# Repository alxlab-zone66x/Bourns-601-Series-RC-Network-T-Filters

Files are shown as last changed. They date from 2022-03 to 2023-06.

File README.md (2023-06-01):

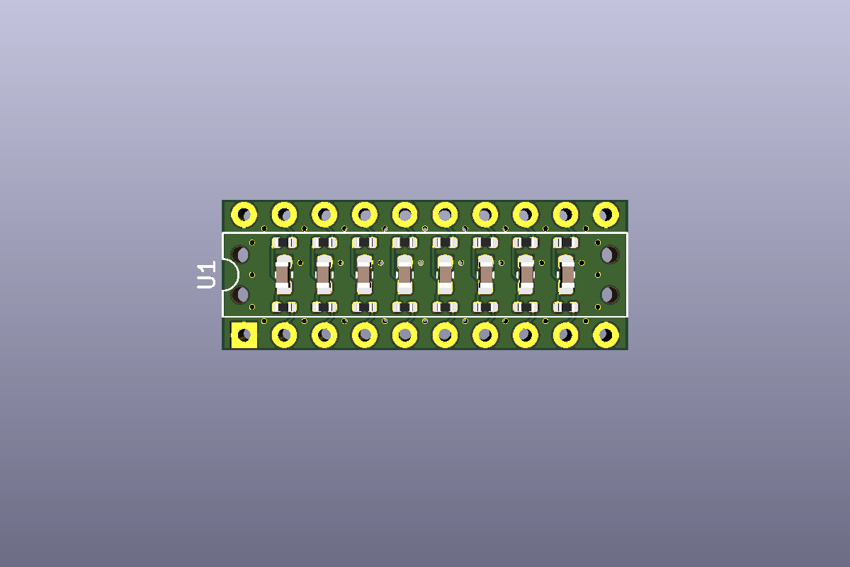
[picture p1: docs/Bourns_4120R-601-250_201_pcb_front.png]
Bourns 4120R-601-250/201 PCB front
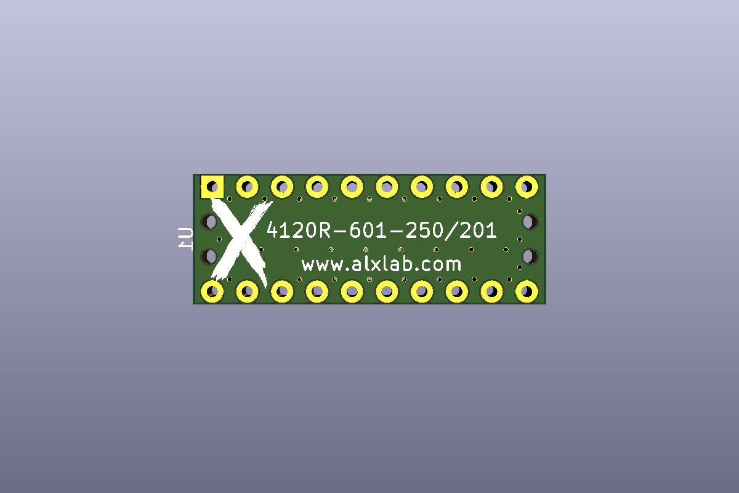
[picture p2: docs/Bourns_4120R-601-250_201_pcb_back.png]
Bourns 4120R-601-250/201 PCB back


# Bourns 601 Series - RC Network T-Filters

This is a recreation the discontinued *Bourns 4120R-601-250/201* DIP used on the Macintosh SE and Macintosh SE/30. The filter chip also goes by the model numbers *M/C 8908L 115-0002*, *CRL 8743L 115-0002* or *P9120M115-0006*. 

Pictures of the chips:

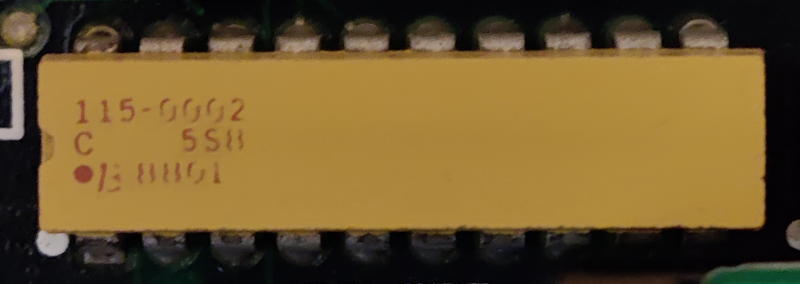
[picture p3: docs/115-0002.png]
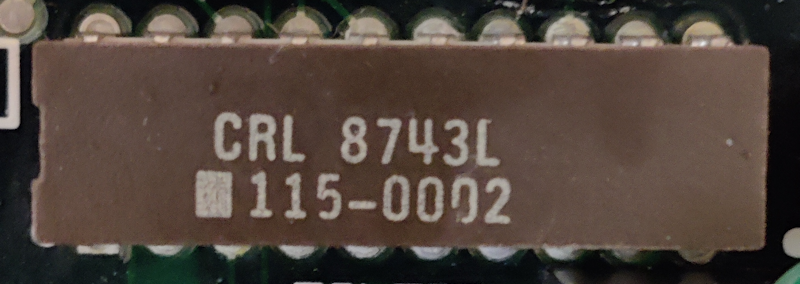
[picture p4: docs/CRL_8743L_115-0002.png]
CRL 8743L 115-0002
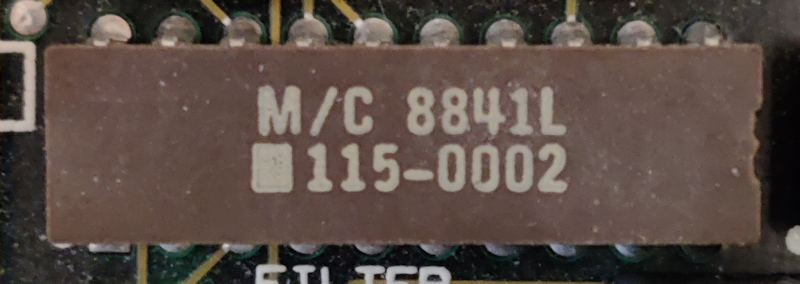
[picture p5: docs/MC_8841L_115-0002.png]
M/C 8841L 115-0002.png


Even though the Kicad and EasyEDA files are geared towards the *4120R-601-250/201* specifically,  the capacitor and resistor values can be changed  to make other discontinued Bourns 601 Series filters:

| Part Number | Resistor Value | Capacitor Value |
| --- | --- | --- |
| 4120R-601-101/101 | 100 ohm | 100 pF |
| 4120R-601-101/181 | 100 ohm | 180 pF |
| 4120R-601-101/201 | 100 ohm | 200 pF |
| 4120R-601-250/101 | 25 ohm | 100 pF |
| 4120R-601-250/181 | 25 ohm | 180 pF |
| 4120R-601-250/201 | 25 ohm | 200 pF |
| 4120R-601-250/500 | 25 ohm | 50 pF |
| 4120R-601-270/101 | 27 ohm | 100 pF |
| 4120R-601-270/201 | 27 ohm | 200 pF |
| 4120R-601-270/500 | 27 ohm | 50 pF |
| 4120R-601-470/101 | 47 ohm | 100 pF |
| 4120R-601-470/201 | 47 ohm | 200 pF |
| 4120R-601-470/500 | 47 ohm | 50 pF |
| 4120R-601-820/101 | 82 ohm | 100 pF |
| 4120R-601-820/201 | 82 ohm | 200 pF |
| 4120R-601-820/500 | 82 ohm | 50 pF |

If the part number your looking for isn't listed, please refer to the [datasheet](docs/datasheets/Bourns_4120R-601-250_201.pdf).

## Bill of Materials

4120R-601-250/201

| Quantity | Description | Designators | Product Number  | Datasheet |
| :--- | --- | --- | --- | --- |
| 16 | 25 Ohm resistor - 0402 (original 25V, ±10%) | R1-R16 | 0402WGF255JTCE  | [datasheet](docs/datasheets/R1-R16_2110260430_UNI-ROYAL-Uniroyal-Elec-0402WGF255JTCE_C129579.pdf) |
| 8 | 200 pF capacitor - 0603 (original Z5U, ±30% capacitance) | C1-C8 | 0603CG201J500NT | [datasheet](docs/datasheets/C1-C8_1811061810_FH-Guangdong-Fenghua-Advanced-Tech-0603B201K500NT_C1600.pdf) |
| 2 | 10-pin male header 0.1" (2.54mm) pitch | | | |

## Manufacturing

The release includes the manufacturing files for JLCPCB specifically for a 8 column and 3 row panel. The pick and place file includes all the components already placed for the panel. I recommend a PCB thickness of 1mm or less if you do panelization to make the PCBs easier to separate.

When you place an order with JLCPCB the `Delivery Format` should be `Panel by Customer` . The `Panel Format` should be `Column: 8` and `Row: 3`. The PCB Thickness should be 1mm.

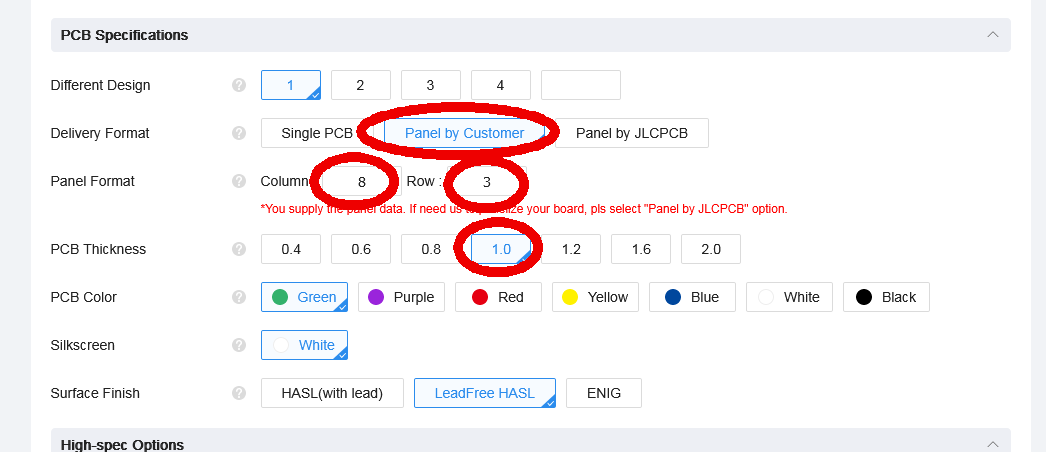
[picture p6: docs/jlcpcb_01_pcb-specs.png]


The PCB preview should look like this:

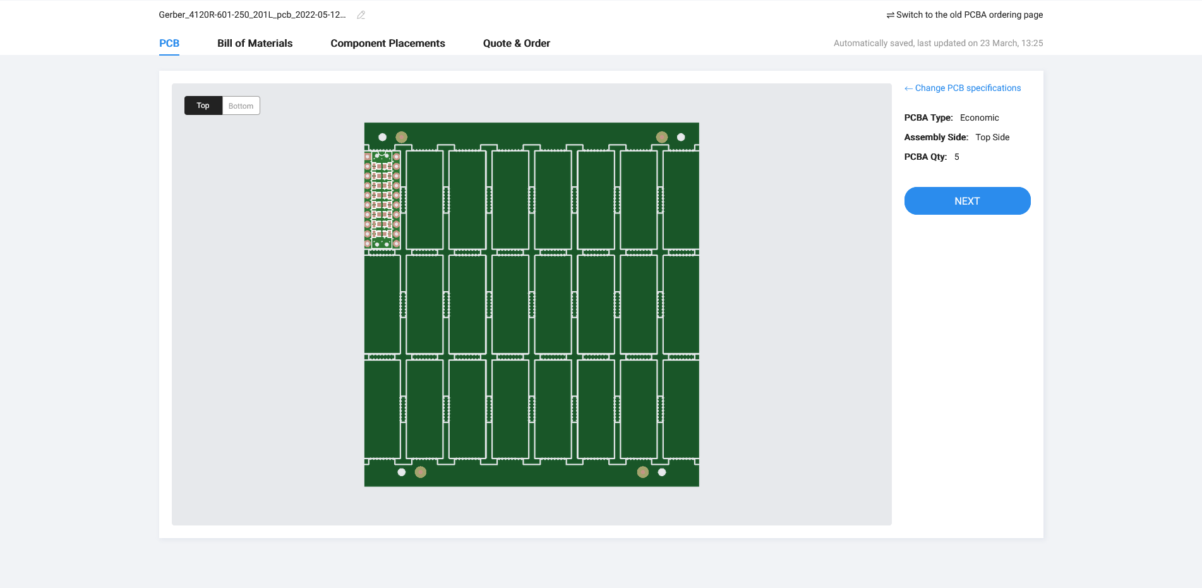
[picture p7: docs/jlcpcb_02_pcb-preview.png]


For the `Bill of Materials`  part of the order where you upload the BOM and Pick and Place files there is an option at the bottom called `File provided as`. You should select `Complete File, just proceed with my own files ` since the pick and place file has all the component placements for the panel.

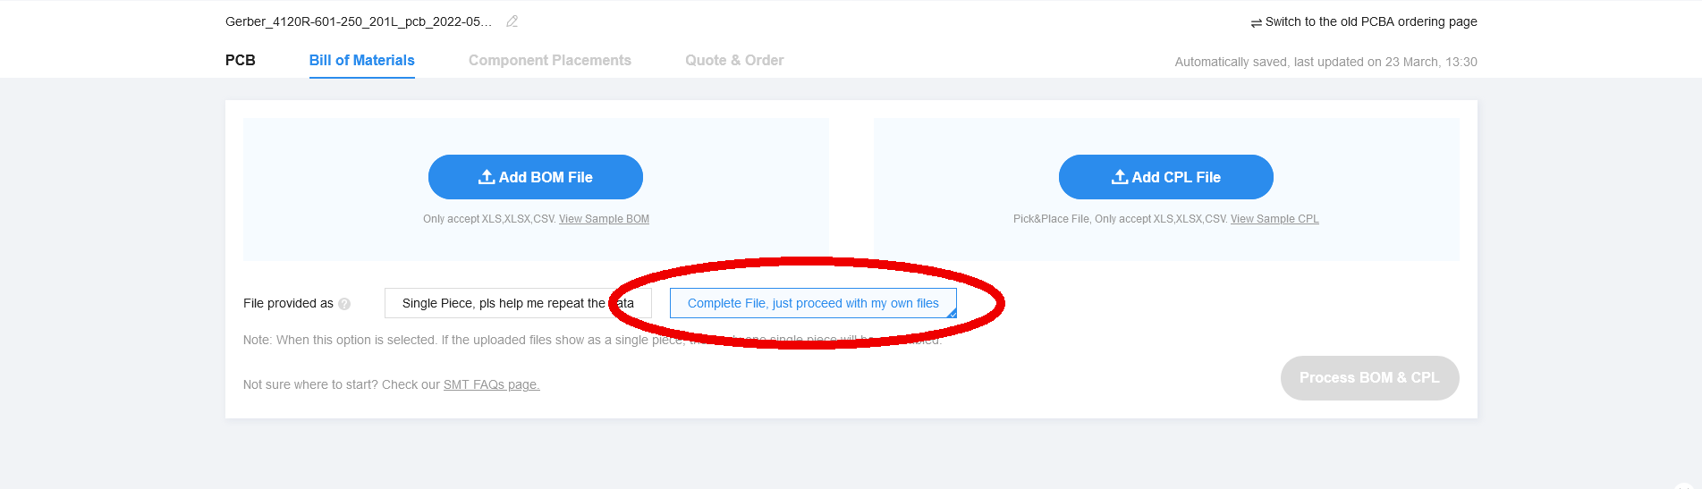
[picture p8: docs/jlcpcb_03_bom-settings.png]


If you had selected everything properly you should have a minimum of 1920 resistors and 960 capacitors for a minimum order of 5 panels. JLCPCB may add a few extra resistors or capacitors to the quantities.

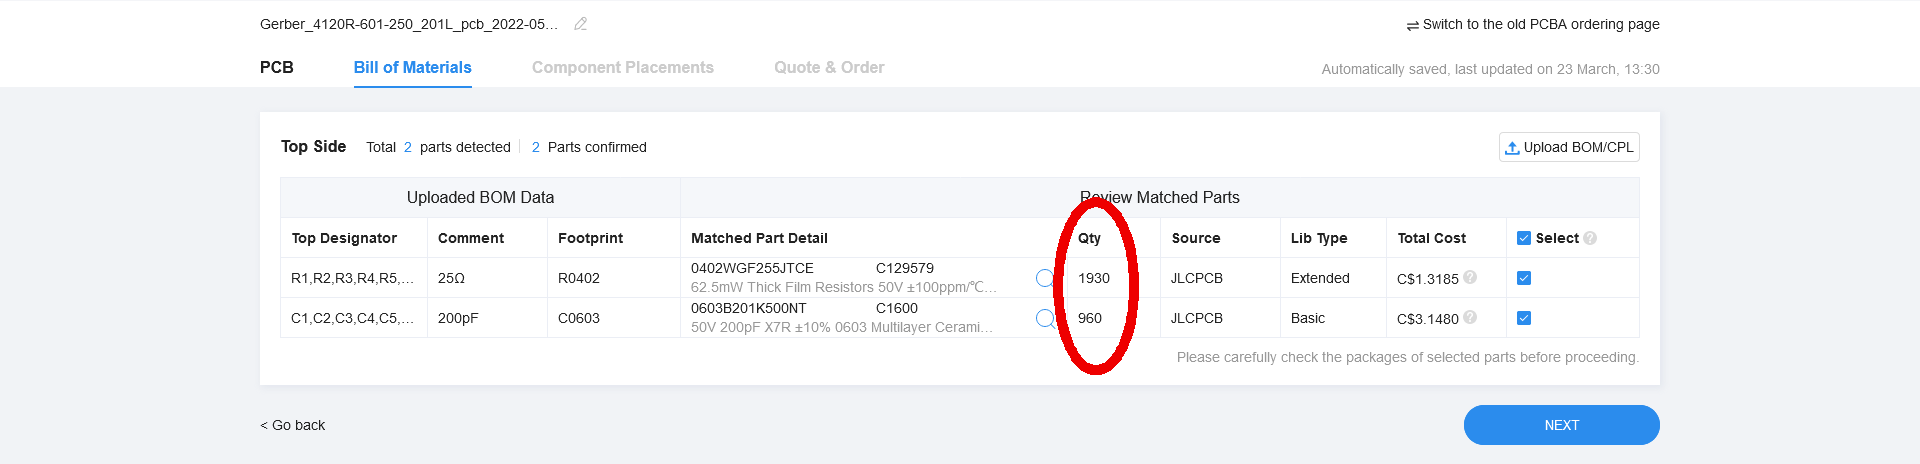
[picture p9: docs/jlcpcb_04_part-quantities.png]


The assembly preview should also show all the components in the right spots. Ignore the fact that the cuts in between the individual PCBs of the panel don't show up in the component placement preview. This is normal when doing the panelization with EasyEDA.

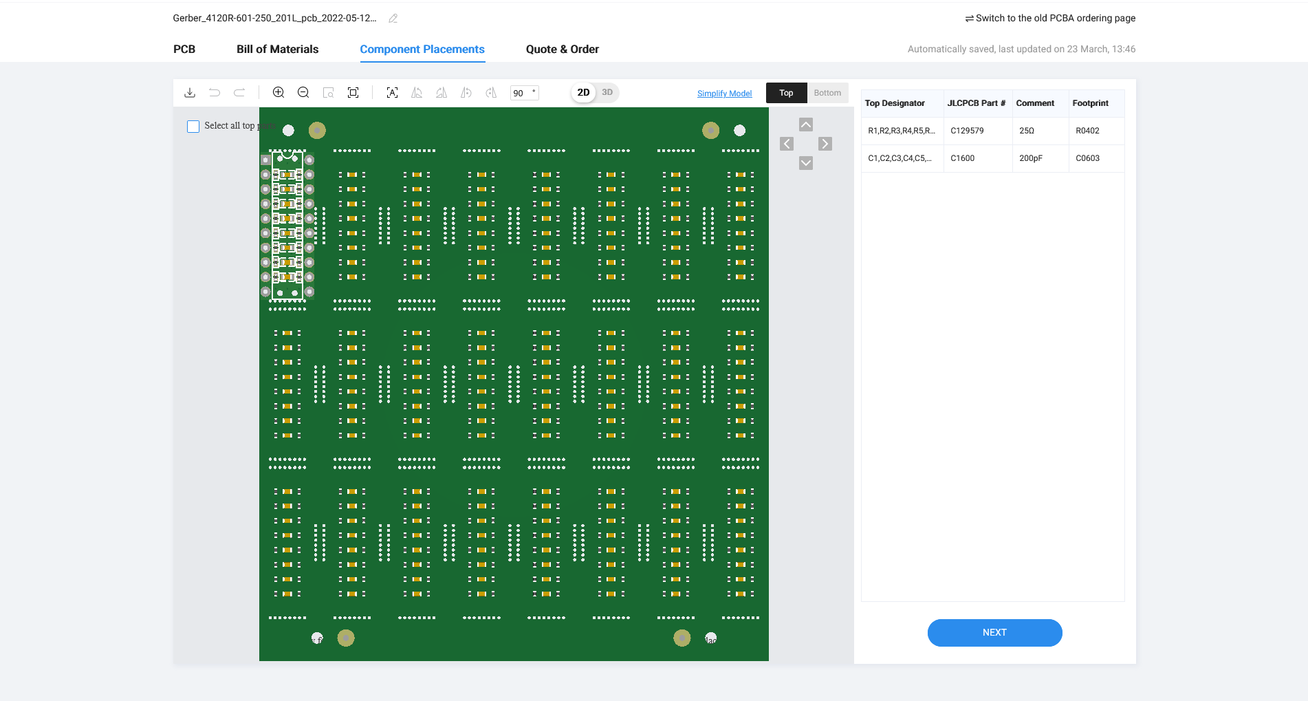
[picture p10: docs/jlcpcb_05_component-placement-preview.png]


**Note:** If you need the gerber files, BOM or component pick & place in a different format then you would have to generate them yourself.

## License



Bourns 601 Series - RC Network T-Filters by [Alexandre Marcoux](https://github.com/alxlab-zone66x/Bourns-601-Series-RC-Network-T-Filters) is licensed under a [Creative Commons Attribution 4.0 International License](http://creativecommons.org/licenses/by/4.0/).

## Community

For more great retro hardware projects and a great community check out:

[Tinker Different](https://tinkerdifferent.com/)

Join us in #skunkworks on [Discord](https://discord.gg/GKcvtgU7P9) to help make retro solutions available to all.

[Discord Open Retro SCSI skunkworks](https://discord.gg/GKcvtgU7P9)

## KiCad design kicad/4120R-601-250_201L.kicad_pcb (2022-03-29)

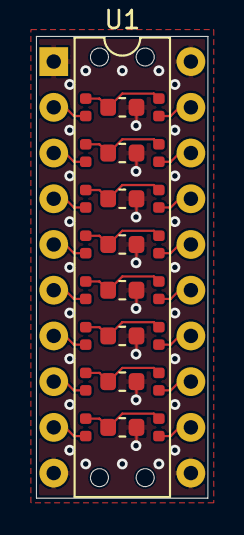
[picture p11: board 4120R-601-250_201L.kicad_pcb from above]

Board: 2 copper layers, 9.5 x 25.7 mm, 25 parts (0 on the bottom side), 25 nets.

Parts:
C1, C2, C3, C4, C5, C6, C7, C8: 200pF; C_0603_1608Metric
R1, R2, R3, R4, R5, R6, R7, R8, R9, R10, R11, R12, R13, R14, R15, R16: 25Ω; R_0402_1005Metric
U1: Bourns_Filter_4120R-601-250_201; DIP-20_W7.62mm

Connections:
GND: C1.2, C2.2, C3.2, C4.2, C5.2, C6.2, C7.2, C8.2, U1.1, U1.10, U1.11, U1.20
unnamed: C1.1, R1.2, R2.1
unnamed: C2.1, R3.2, R4.1
unnamed: C3.1, R5.2, R6.1
unnamed: C4.1, R7.2, R8.1
unnamed: C5.1, R9.2, R10.1
unnamed: C6.1, R11.2, R12.1
unnamed: C7.1, R13.2, R14.1
unnamed: C8.1, R15.2, R16.1
unnamed: R1.1, U1.2
unnamed: R2.2, U1.19
unnamed: R3.1, U1.3
unnamed: R4.2, U1.18
unnamed: R5.1, U1.4
unnamed: R6.2, U1.17
unnamed: R7.1, U1.5
unnamed: R8.2, U1.16
unnamed: R9.1, U1.6
unnamed: R10.2, U1.15
unnamed: R11.1, U1.7
unnamed: R12.2, U1.14
unnamed: R13.1, U1.8
unnamed: R14.2, U1.13
unnamed: R15.1, U1.9
unnamed: R16.2, U1.12

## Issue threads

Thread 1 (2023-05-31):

JLPCB Resistor Count Mismatch

E1L3VN, 2023-05-31:
Hey Alxlab,

Thanks for the amazing work recreating these filters. I was hoping to order some boards to replace all four filters on a Macintosh Plus board that I'm attempting to repair. I haven't been able to find anywhere stocking the original part anymore.

After uploading the Gerber, BOM and PickAndPlace however I'm running into an issue on JLPCB, where the parts summary lists **1925** resistors instead of the 1930 you mention in the documentation:

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

Any assistance you could provide with this matter would be most appreciated.

E1L3VN, 2023-06-02:
Thanks Alx!

Appreciate the prompt clarification!

Closed 2023-06-02.

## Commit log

2022-03-29 Version 1
    [4120R-601-250_201L.kicad_pcb, 4120R-601-250_201L.sch]
2022-05-12 Fix BOM part numbers
2022-05-12 Change gerber archive name
2022-05-24 Update README to include manufacturing details and better BOM

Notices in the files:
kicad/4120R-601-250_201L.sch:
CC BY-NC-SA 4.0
